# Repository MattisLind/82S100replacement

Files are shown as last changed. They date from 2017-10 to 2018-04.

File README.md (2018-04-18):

# 82S100replacement
A CPLD implementation of the classic 82S100/82S101 as used in for example C64

82S100 replacement

The WinCUPL code is taken directly from the [VHDL](https://bitbucket.org/skoe/pla) made by Thomas 'skoe' Giesel and simply translated into WinCUPL. Skoe made an excellent [description](http://skoe.de/docs/c64-dissected/pla/c64_pla_dissected_r1.1_a4ds.pdf) on the C64 PLA which is very well worth reading.

The small board is available as a shared project at [OSHPark](https://oshpark.com/shared_projects/fJN4h1Z9). Anyone is welcome to use the production files, Diptrace files and WinCUPL the way they like. But don't blame me if you get problems (or destroy your computer or someone else's computer...). It works fine for me and your mileage may vary.

Yes. I am aware that I did a small mistake in that the JTAG connector doesn't have 0.1" pitch.

In C64

Compared with other C64 PLA replacements this one is more generic 82S100 or 82S101 replacement since the #OE signal is provided at pin 19 and there is no special buffering on the outputs so they can be either tristate or open collector as the designer of the WinCUPL file wishes.

The CPLD used is an Atmel ATF1502ASL-25AU44. The good thing with this Atmel part is that it is 5V. Not just 5V tolerant. The L variant is also Low power and the slowest part which is good when emulating old parts. Mouser order# [556-AF1502ASL25AU44](http://www.mouser.se/Search/ProductDetail.aspx?R=ATF1502ASL-25AU44). The decoupling capacitor is a 0.22uF ceramic. Mouser order# [80-C0805C224K5R](http://www.mouser.se/Search/ProductDetail.aspx?R=C0805C224K5RACTU). The cheapest way to get the connecting pins is to order them from Aliexpress. Search for ["Gold Plated 2.54mm Male 40 Pin Single Row Straight Round Pin Header Strip"](https://www.aliexpress.com/af/Gold-Plated-2.54mm-Male-40-Pin-Single-Row-Straight.html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)

Since EPM7032S is pin compatible it can be used as well as far as I can see. However the vendor has discontinued their 5V line. Although devices can probably be found from surplus sellers.

To program the part you need to download the [WinCUPL](https://www.microchip.com/design-centers/programmable-logic/spld-cpld/tools/software/wincupl) software fomr Atmel site. It is free and runs under Windows. Then to download your design to the chip you need a JTAG ISP cable, ATDH1150USB-K.

[jamarju](https://github.com/jamarju) contributed with information on a cheaper way to program the Atmel devices:

As an alternative, if you have an old computer with LPT1, you can build this cable:

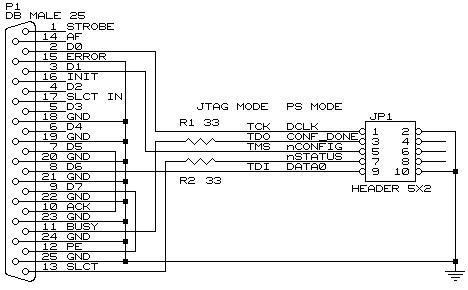
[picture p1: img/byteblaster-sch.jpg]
Atmel CPLD LPT programmer


I used a cut out USB cable to get the 5V for VREF and tied the DB-25 and USB GNDs together. Also pin 13 out of the DB-25 is not needed, so the only components needed are 1x 33 ohm and 1x DB-25 male connector.

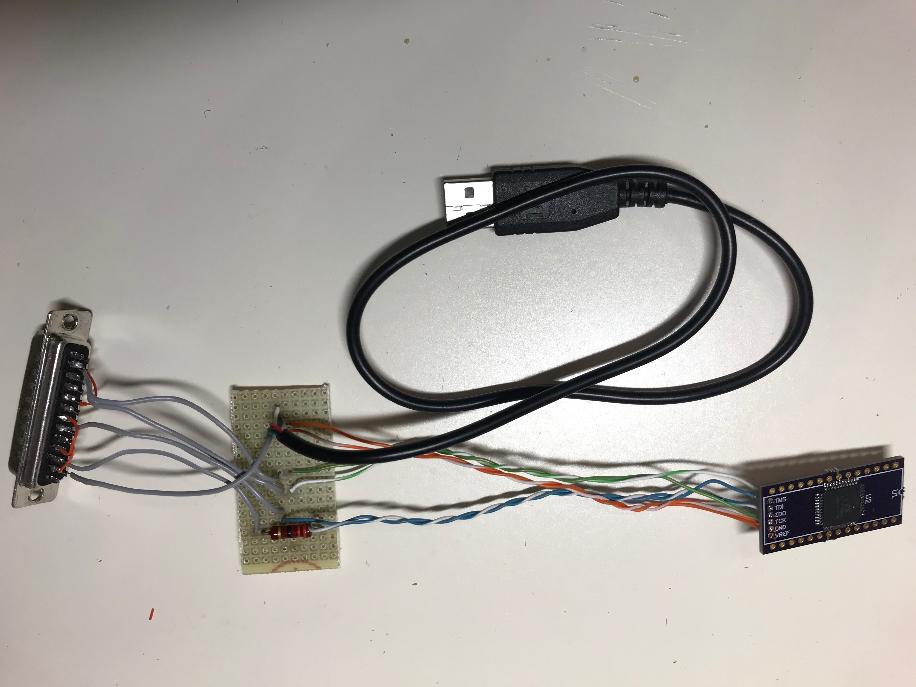
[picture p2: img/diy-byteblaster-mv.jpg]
DIY byteblaster


Use the older XP/2000 [ATMISP v6.7](https://www.microchip.com/design-centers/programmable-logic/spld-cpld/tools/software/atmisp) version and choose "ByteBlasterMV" as programmer:

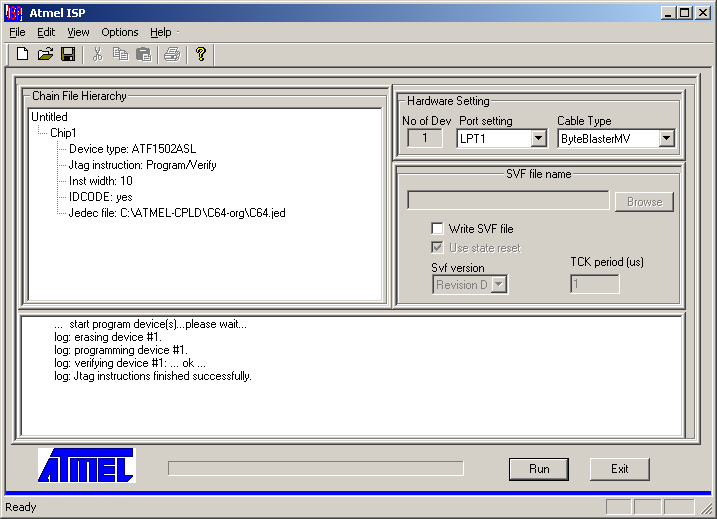
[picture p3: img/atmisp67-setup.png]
ATMISP setup


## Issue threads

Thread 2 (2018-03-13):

Unable to program

patzik, 2018-03-13:
I had  some pcb's made and tried to build the 82s100 replacement.
I build the lpt cable to program the cpld but I keep getting an error.
"hardware and software settings mismatch"
Any suggestions?
I use a PCIe card with a parallel port, it's lpt1 and the adress is CEFC-CEFF (I/O Range)
I use windows 8, and also tried it  on a virtual machine running xp. Same problem...

MattisLind, 2018-03-13:
I haven’t tried to use the LPT dongle myself. I always used the USB JTAG dongle. This was controbuted by Github user @jamarju  , you have to ask him.

jamarju, 2018-03-13:
Double check the schematic taking into account that some pins in the DB25 port loop back: D7-PE, ERROR-GND and D5-ACK. Also make sure you are using version 6.7 of ATMISP, I think that's the only one that supports LPT1 programmers. Also I would try using the standard 378 port just to rule that out.

jamarju, 2018-03-13:
Oh, and no virtual machines. I think the timings are critical here.

patzik, 2018-03-13:
It's not really a dongle, but internal PCIe card.
I figured I had and old pc somewhere in storage and I dug it up, it had an onboard parallel port so I installed xp and the Atmel ISP. This port has address 0378 which is the standard IO address.
Works like a charm now, so the cable is fine. I would like to get it to work on my regular pc, but I think the IO address is the cause of the problem, strange because you can actually select the address in the programmer software instead of lpt1

jamarju, 2018-03-14:
It may be because of I/O to that port going through additional circuitry and/or driver virtualization, who knows. Anyway I'm glad it worked, enjoy @MattisLind 's PLA, I made one for my breadbin C64 and it works great :)

pazuzu72, 2018-05-24:
Hi, can this project also be used for the C16 / Plus-4, obviously replacing the suitable .PLD? :-)

MattisLind, 2018-05-24:
I don't know much about what kind of PLA was used in thus computers. As long as it is a 82S100/82S101 it should be possible I think. According to this page it is a 82S100. http://www.zimmers.net/anonftp/pub/cbm/firmware/computers/plus4/pla.c  You have convert the equations to CUPL however.

MattisLind, 2019-12-20:
I close this issue since there has been long time and the fact it is most likely related to the hardware used.

Closed 2019-12-20.
